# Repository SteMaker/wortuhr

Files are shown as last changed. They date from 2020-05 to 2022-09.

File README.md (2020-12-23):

# Wortuhr
Wortuhr basierend auf ESP-12F inkl. Firmware, PCB und Hardware-Beschreibung.

Ich übernehme keinerlei Verantwortung für die Funktionsfähigkeit und Sicherheit dieses Projekts. Jeder, der es nachbaut, ist selbst dafür verantwortlich!

Die Idee und insbesondere die Anordnung der Buchstaben habe ich mir im FabLab Nürnberg abgeschaut. Vielen Dank an der Stelle an den Unbekannten! :)

Die Hardware besteht aus 11 LED-Streifen à 11 LEDs vom Typ WS2812, die RGB fähig sind. Als Controller dient ein ESP-12F (ESP8266), der sich die Uhrzeit über das Internet per NTP holt. Die Konfiguration wird über ein Webinterface vorgenommen. Ein Helligkeitssensor wird verwendet, um die Helligkeit der Uhr (falls gewünscht) automatisch anzupassen. Es gibt auch eine Möglichkeit die Uhr zu einer bestimmten Zeit dunkel zu schalten, und zu einer anderen Zeit wieder zu aktivieren. Außerdem kann man die Farbe der LEDs pro Wort einstellen.

## Weitere Infos und die Bauanleitung sind im [Wiki](https://github.com/SteMaker/wortuhr/wiki)

## Aufbau
Als LED-Streifen werden WS2812 verwendet. Für jede der 11 Zeilen wird ein Streifen mit 11 LEDs verwendet. Die Spannungsversorgung habe ich für jeden Streifen einzeln auf die Hauptplatine gezogen, die Datenleitung muss von `Dout` des einen Streifens zum `Din` des Streifens der nächsten Zeile gezogen werden. Der `Din` der ersten Zeile muss rechts oben liegen und wird mit dem Controller verbunden. Von der linken Seite der ersten Zeile geht dann der `Dout` zum `Din` der linken Seite des zweiten Streifens, usw. Das ist wichtig, da sonst die falschen Buchstaben aufleuchten. Ich verwende LED Streifen mit 60 LEDs pro Meter.

Die Buchstabenmatrix habe ich mit einem 3D-Drucker ausgedruckt. Die STL-Dateien sowie die SVG-Basis liegen im Ordner `rahmen`. Es gibt eine Rückseite, in die die 11 LED-Streifen geklebt werden und eine Vorderseite mit den Aussparungen für die Buchstaben. Das Ganze kommt dann in einen Bilderrahmen. Der IKEA RIBBA 23x23 passt perfekt.

Alternativ kann die Frontplatte aus lackiertem Acrylglas gelasert werden.

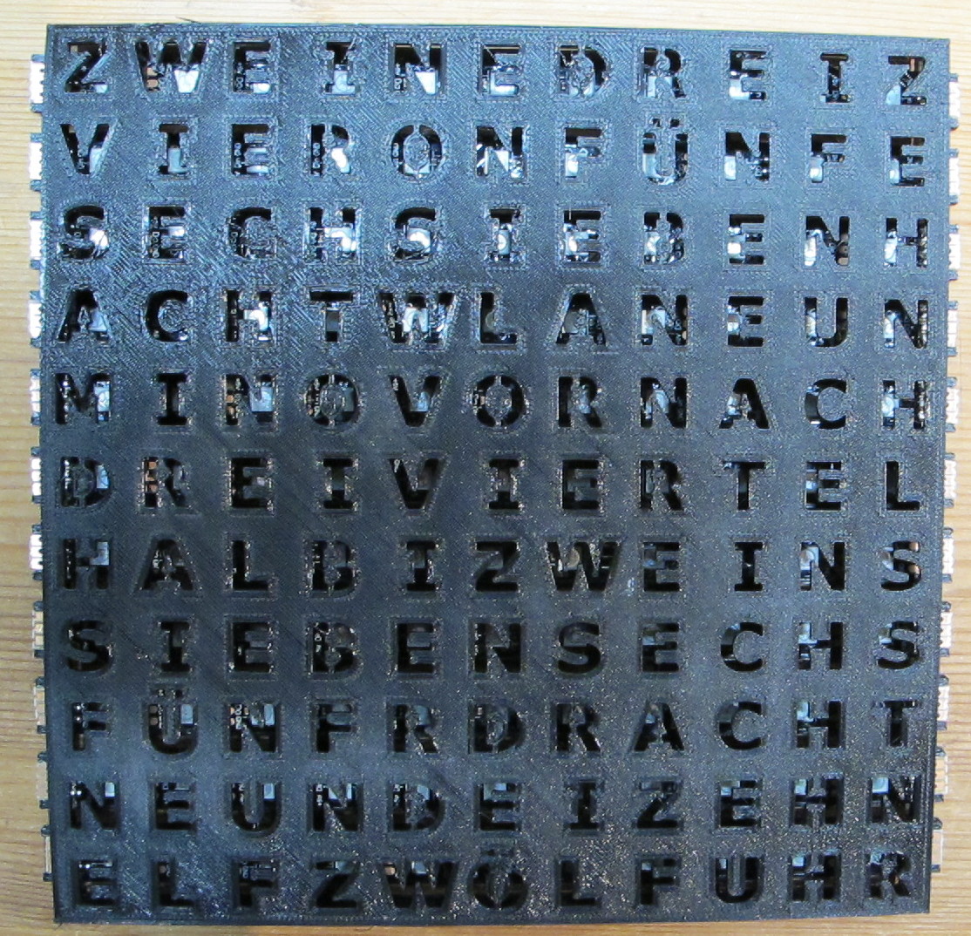
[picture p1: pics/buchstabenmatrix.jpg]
Buchstabenmatrix


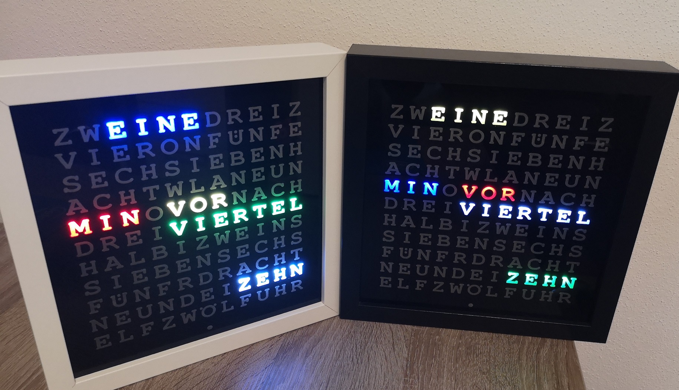
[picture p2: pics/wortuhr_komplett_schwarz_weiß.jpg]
Wortuhr mit gelaserter Acrylfront


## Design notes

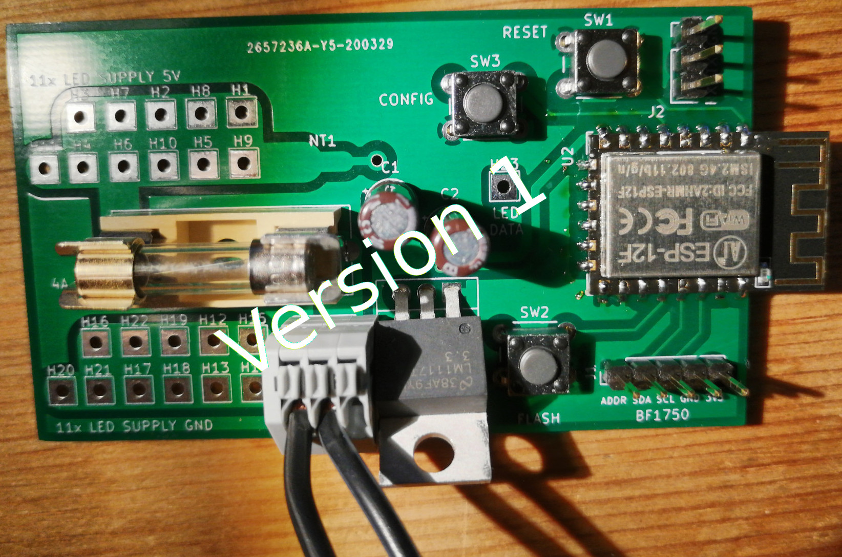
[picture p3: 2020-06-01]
pics/pcb1.jpg

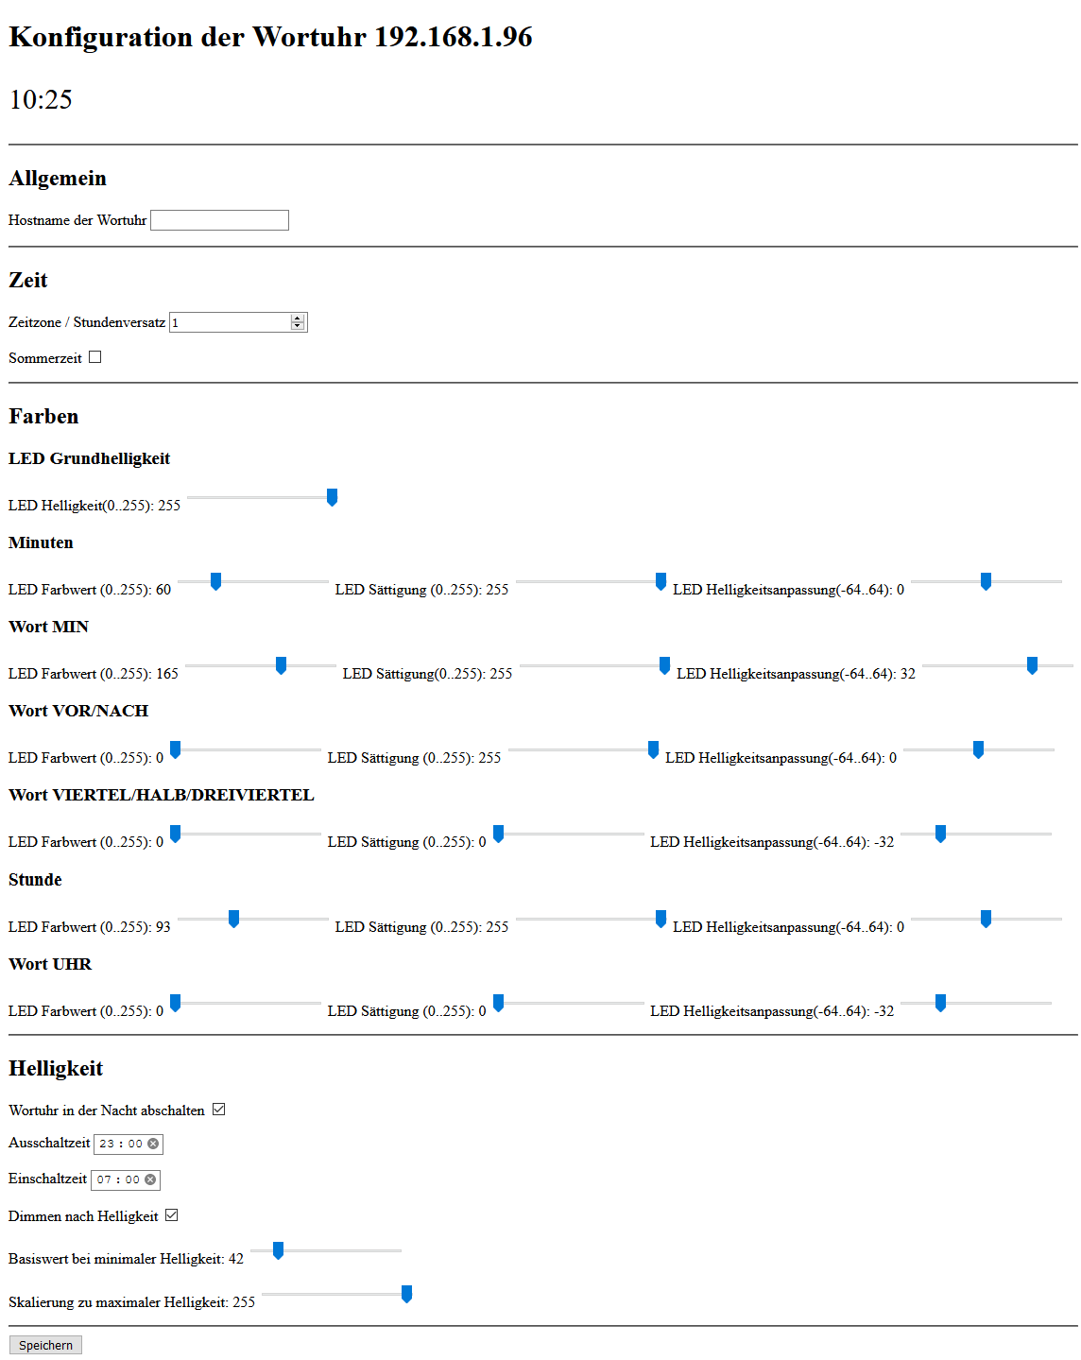
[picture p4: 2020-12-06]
pics/konfiguration.png

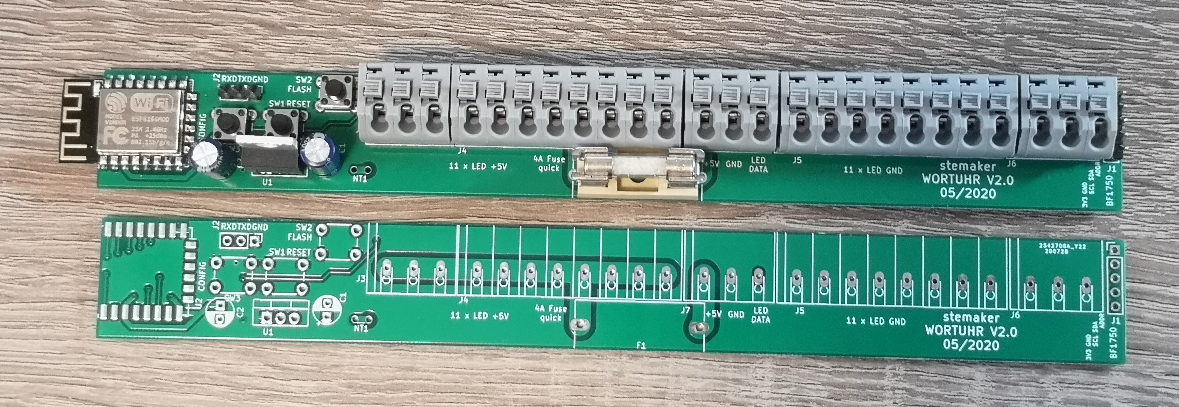
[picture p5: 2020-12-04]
pics/pcb_v2.jpg

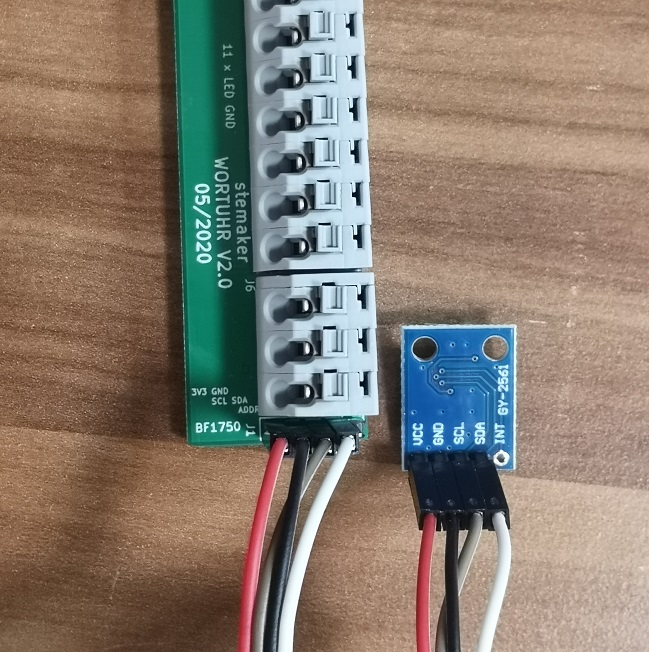
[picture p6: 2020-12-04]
pics/anschluss_helligkeitssensor_tsl2561.jpg

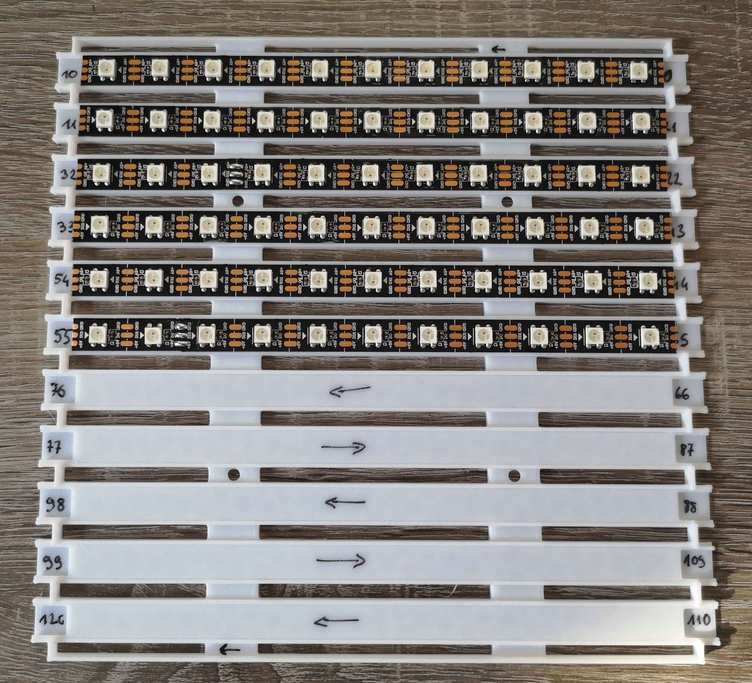
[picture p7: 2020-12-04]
pics/rueckseite_bestueckt_richtung.jpg

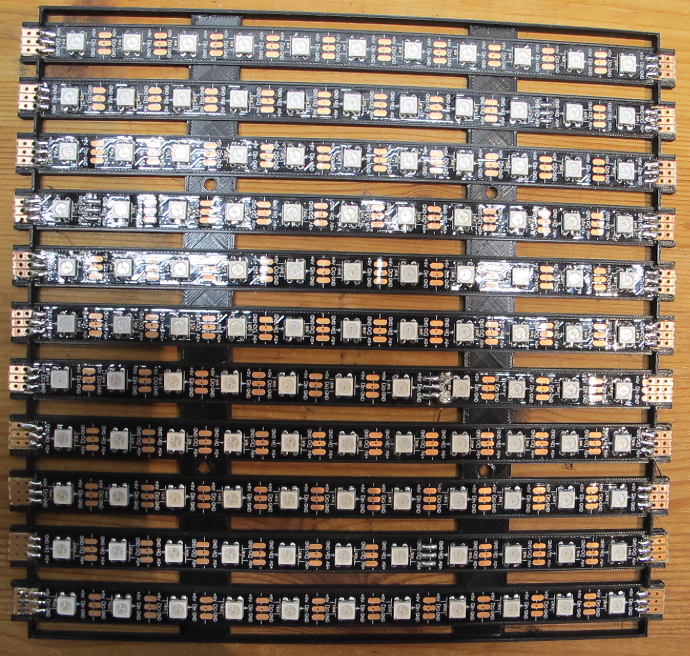
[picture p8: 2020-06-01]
pics/rueckseite_bestueckt.jpg

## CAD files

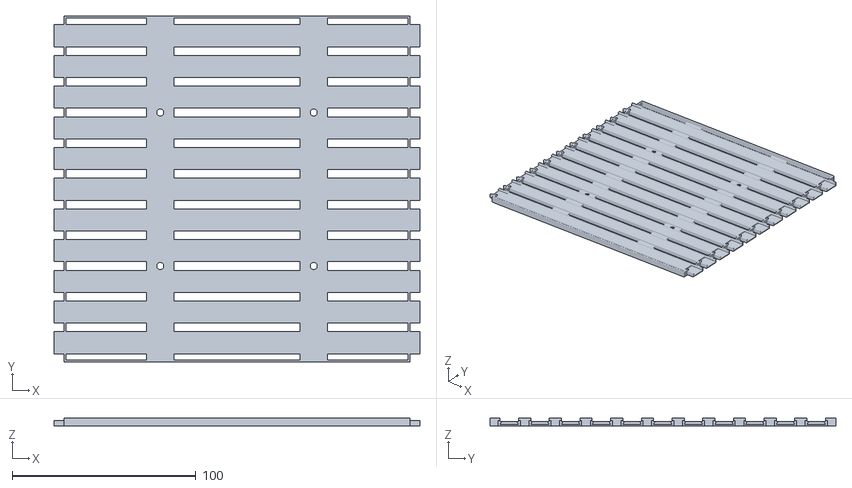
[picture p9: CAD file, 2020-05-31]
rahmen/Wortuhr_Rückteil.stl
199.0 x 188.0 x 4.60

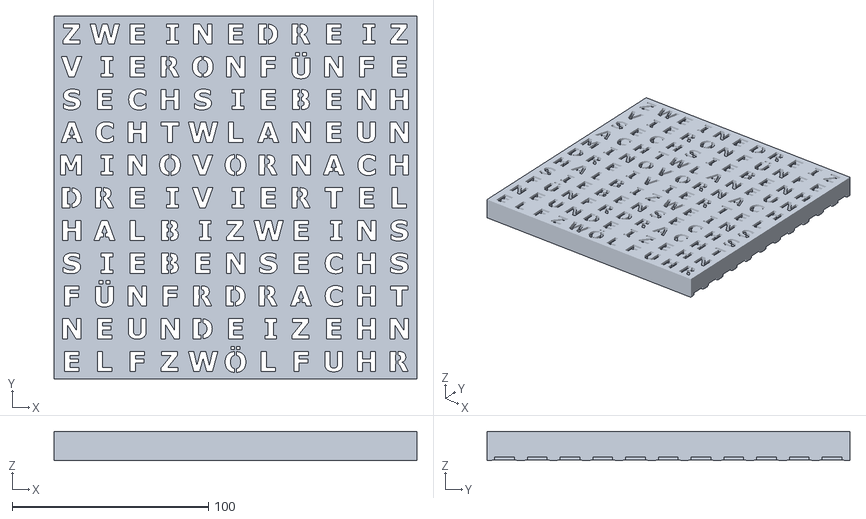
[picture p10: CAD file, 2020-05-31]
rahmen/Wortuhr_Vorderteil.stl
185.0 x 185.0 x 15.0

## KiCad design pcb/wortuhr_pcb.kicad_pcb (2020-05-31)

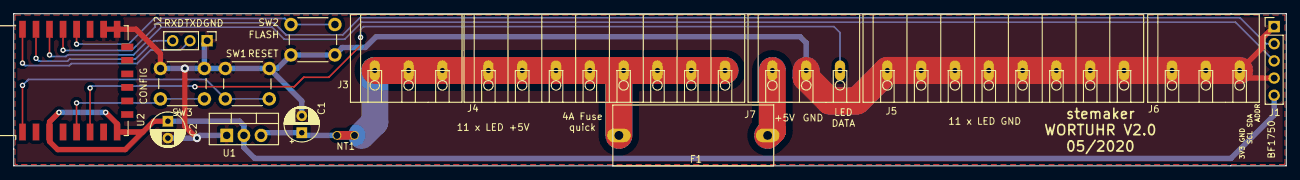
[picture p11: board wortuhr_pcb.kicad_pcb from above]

Board: 2 copper layers, 188.2 x 22.5 mm, 16 parts (0 on the bottom side), 13 nets.

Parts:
C1, C2: 1µF; CP_Radial_D5.0mm_P2.50mm
F1: Fuse; RND_fuse_holder_5x20mm_horizontal
J1: Conn_01x05_Male; PinHeader_1x05_P2.54mm_Vertical
J2: Conn_01x03_Male; PinHeader_1x03_P2.54mm_Vertical
J3, J6, J7: Conn_01x03_Male; WAGO_250-503
J4, J5: Conn_01x08_Male; WAGO_250-508
NT1: Net-Tie_2; NetTie-2_THT_Pad1.0mm
SW1, SW2, SW3: SW_Push; SW_PUSH_6mm_H4.3mm
U1: LM1117-3.3; TO-220-3_Vertical
U2: ESP-12F; ESP-12E

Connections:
+3V3: C2.1, J1.5, U1.2, U2.3, U2.8
+5V: C1.1, NT1.2, U1.3
/CFG: SW3.1, U2.5
/FLASH: SW2.1, U2.18
/LED_5V: F1.1, J3.1, J3.2, J3.3, J4.1, J4.2, J4.3, J4.4, J4.5, J4.6, J4.7, J4.8, NT1.1
/LED_DATA: J7.3, U2.6
/MAIN_SUPPLY: F1.2, J7.1
/RESET: SW1.2, U2.1
/RXD: J2.3, U2.21
/SCL: J1.3, U2.20
/SDA: J1.2, U2.19
/TXD: J2.2, U2.22
GND: C1.2, C2.2, J1.1, J1.4, J2.1, J5.1, J5.2, J5.3, J5.4, J5.5, J5.6, J5.7, J5.8, J6.1, J6.2, J6.3, J7.2, SW1.1, SW2.2, SW3.2, U1.1, U2.15, U2.16

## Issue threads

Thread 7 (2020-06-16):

Exception if clock is booted while website is loaded in browser

stan23, 2020-06-16:
If the wordclock website is open in a browser while the wordclock is powered up and booted, there's an exception.

First `NO WLAN` is shown, then `WLAN`, then the exception happens and the clock reboots.

Stack trace:
```
Exception 9: LoadStoreAlignmentCause: Load or store to an unaligned address
PC: 0x4010565c
EXCVADDR: 0x00000003

Decoding stack results
0x40220cb1: dns_gethostbyname_addrtype at core/dns.c line 1502
0x40220d08: dns_gethostbyname at core/dns.c line 1530
0x40229040: mem_free at core/mem.c line 237
0x402226f4: tcp_input at core/tcp_in.c line 501
0x402282ce: ip4_input at core/ipv4/ip4.c line 1467
0x4021f195: ethernet_input_LWIP2 at netif/ethernet.c line 188
0x4021efb4: esp2glue_ethernet_input at glue-lwip/lwip-git.c line 469
0x402449ce: ethernet_input at glue-esp/lwip-esp.c line 365
0x402449df: ethernet_input at glue-esp/lwip-esp.c line 373
0x4021eb79: glue2esp_linkoutput at glue-esp/lwip-esp.c line 301
0x4021ee02: new_linkoutput at glue-lwip/lwip-git.c line 260
0x4021f220: ethernet_output at netif/ethernet.c line 312
0x40229020: mem_malloc at core/mem.c line 210
0x4021f275: do_memp_malloc_pool at core/memp.c line 255
0x4021f2b4: memp_malloc at core/memp.c line 356
0x40226ad7: etharp_query at core/ipv4/etharp.c line 1031
0x4021eb79: glue2esp_linkoutput at glue-esp/lwip-esp.c line 301
0x40226c48: etharp_output_LWIP2 at core/ipv4/etharp.c line 890
0x40228530: ip4_output_if_opt_src at core/ipv4/ip4.c line 1764
0x4021f220: ethernet_output at netif/ethernet.c line 312
0x402285c6: ip4_output_if_src at core/ipv4/ip4.c line 1590
0x4022912b: ip_chksum_pseudo at core/inet_chksum.c line 395
0x402235ec: udp_sendto_if_src at core/udp.c line 893
0x40223643: udp_sendto_if at core/udp.c line 692
0x402236dc: udp_sendto at core/udp.c line 599
0x402206ba: dns_send at core/dns.c line 850
0x4022079b: dns_check_entry at core/dns.c line 1096
0x40220cb1: dns_gethostbyname_addrtype at core/dns.c line 1502
```

```
Exception 9: LoadStoreAlignmentCause: Load or store to an unaligned address
PC: 0x4010565c
EXCVADDR: 0x00000003

Decoding stack results
0x40229040: mem_free at core/mem.c line 237
0x402226f4: tcp_input at core/tcp_in.c line 501
0x402282ce: ip4_input at core/ipv4/ip4.c line 1467
0x4021f195: ethernet_input_LWIP2 at netif/ethernet.c line 188
0x4021efb4: esp2glue_ethernet_input at glue-lwip/lwip-git.c line 469
0x402449ce: ethernet_input at glue-esp/lwip-esp.c line 365
0x402449df: ethernet_input at glue-esp/lwip-esp.c line 373
0x4021eb79: glue2esp_linkoutput at glue-esp/lwip-esp.c line 301
0x4021ee02: new_linkoutput at glue-lwip/lwip-git.c line 260
0x4021f220: ethernet_output at netif/ethernet.c line 312
0x4021eb79: glue2esp_linkoutput at glue-esp/lwip-esp.c line 301
0x4021ee02: new_linkoutput at glue-lwip/lwip-git.c line 260
0x4021f220: ethernet_output at netif/ethernet.c line 312
0x4022912b: ip_chksum_pseudo at core/inet_chksum.c line 395
0x40229020: mem_malloc at core/mem.c line 210
0x4021f275: do_memp_malloc_pool at core/memp.c line 255
0x4021f2b4: memp_malloc at core/memp.c line 356
0x40226ad7: etharp_query at core/ipv4/etharp.c line 1031
0x40223643: udp_sendto_if at core/udp.c line 692
0x40226c48: etharp_output_LWIP2 at core/ipv4/etharp.c line 890
0x402206ba: dns_send at core/dns.c line 850
0x40228530: ip4_output_if_opt_src at core/ipv4/ip4.c line 1764
0x4022079b: dns_check_entry at core/dns.c line 1096
0x402285c6: ip4_output_if_src at core/ipv4/ip4.c line 1590
0x4022912b: ip_chksum_pseudo at core/inet_chksum.c line 395
0x402235ec: udp_sendto_if_src at core/udp.c line 893
0x40223643: udp_sendto_if at core/udp.c line 692
0x402236dc: udp_sendto at core/udp.c line 599
```

SteMaker, 2020-06-16:
Crash seems to occur here: https://github.com/SteMaker/wortuhr/blob/master/fw/src/main.cpp#L148.

SteMaker, 2020-06-28:
There is a potential fix on branch add_locks_issues_7. I couldn't reproduce any longer, but was rarely able to reproduce anyway. @stan23 Can you retest with this change?

stan23, 2020-06-28:
Just tried it, 0 crashes out of 10 reboots.
Without the fix it crashed 2 of 5 times.

SteMaker, 2020-07-05:
Fixed with 06bdd98a2ad62b2d2af1609e76567b8c02e3f333

Closed 2020-07-05.

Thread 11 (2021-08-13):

delay() does not work all the time

stan23, 2021-08-13:
Last year when I implemented `showIP()` the `delay()` worked fine, but now is does not wait long enough once Wifi is connected.

It happens with both Arduino Core 2.x and 3.x.

```
Connecting to SSID: TheresNoPlaceLike127001
showNoWlan
DBG: delay of 500 ms took 500 ms
.
DBG: delay of 500 ms took 500 ms
.
DBG: delay of 500 ms took 500 ms
.
DBG: delay of 500 ms took 500 ms
.
DBG: delay of 500 ms took 500 ms
.
DBG: delay of 500 ms took 500 ms
.
DBG: delay of 500 ms took 500 ms
.
showWlan                  <-- from here Wifi is connected
DBG: delay of 1000 ms took 0 ms
I2C device found at address 0x39
IP Address: 192.168.1.109
showIp: 192.168.1.109
DBG: delay of 750 ms took 0 ms
DBG: delay of 750 ms took 0 ms
DBG: delay of 750 ms took 0 ms
DBG: delay of 1000 ms took 0 ms
DBG: delay of 750 ms took 0 ms
DBG: delay of 750 ms took 0 ms
DBG: delay of 750 ms took 0 ms
DBG: delay of 1000 ms took 0 ms
DBG: delay of 750 ms took 0 ms
DBG: delay of 1000 ms took 0 ms
DBG: delay of 750 ms took 0 ms
DBG: delay of 750 ms took 0 ms
DBG: delay of 750 ms took 0 ms
DBG: delay of 1000 ms took 0 ms
Setup done
```

**Impact:**
As shown in the log above, the IP address is flashed within almost no time and hardly visible to the user.

**Root cause analysis:**
`esp_yield()` returns almost immediately and therefore `delay()` returns almost immediately.
Might be related to Wifi behavior impacting the schedule.
I have not found any other bug report on a similar topic.

**Possible solution:**
Change `showIP()` implementation so that it does not rely on `delay()`, which is bad design anyway.
https://github.com/esp8266/Arduino/blob/master/cores/esp8266/core_esp8266_wiring.cpp#L53

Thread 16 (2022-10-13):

Initial upload nicht möglich

Dave2526, 2022-10-13:
Hallo, ich versuche gerade den Intitial Upload zu starten, jedoch kommt immer die unten gezeigt Fehlermeldung. Ich finde lieder keine brauchbare Hilfe dieses Problem zu lösen...

 *  Task wird ausgeführt: C:\Users\User\.platformio\penv\Scripts\platformio.exe run --target upload --environment inital_upload

Processing inital_upload (platform: espressif8266@^2; board: esp12e; framework: arduino)
-----------------------------------------------------------------------------------------------------------------------------------------------------------------------------
Verbose mode can be enabled via `-v, --verbose` option
CONFIGURATION: https://docs.platformio.org/page/boards/espressif8266/esp12e.html
PLATFORM: Espressif 8266 (2.7.4+9) > Espressif ESP8266 ESP-12E
HARDWARE: ESP8266 80MHz, 80KB RAM, 4MB Flash
PACKAGES:
 - framework-arduinoespressif8266 @ 2.7.4+9
 - tool-esptool @ 1.413.0 (4.13)
 - tool-esptoolpy @ 1.30300.220323 (3.3.0)
 - tool-mklittlefs @ 1.203.200522 (2.3)
 - tool-mkspiffs @ 1.200.0 (2.0)
 - toolchain-xtensa @ 2.40802.200502 (4.8.2)
LDF: Library Dependency Finder -> https://bit.ly/configure-pio-ldf
LDF Modes: Finder ~ chain, Compatibility ~ soft
Found 38 compatible libraries
Scanning dependencies...
Dependency Graph
|-- NTPClient @ 3.2.1+sha.78d4237
|-- FastLED @ 3.5.0+sha.0838804
|   |-- SPI @ 1.0
|   |-- EspSoftwareSerial @ 6.10.0
|-- ESP Async WebServer @ 1.2.3+sha.f71e3d4
|   |-- ESPAsyncTCP @ 1.2.2
|   |   |-- ESP8266WiFi @ 1.0
|   |-- Hash @ 1.0
|   |-- ESP8266WiFi @ 1.0
|-- ESP_EEPROM @ 2.1.2+sha.63796bc
|-- CRCx @ 0.3.2+sha.ccaab2a
|-- BH1750FVI @ 1.1.1+sha.1e18959
|   |-- Wire @ 1.0
|-- TSL2561 Arduino Library @ 1.0.0+sha.fea818e
|   |-- Wire @ 1.0
|-- ArduinoJson
|-- ESP8266WiFi @ 1.0
|-- ESPAsyncTCP @ 1.2.2
|   |-- ESP8266WiFi @ 1.0
|-- Wire @ 1.0
|-- ArduinoOTA @ 1.0
|   |-- ESP8266WiFi @ 1.0
|   |-- ESP8266mDNS @ 1.2
|   |   |-- ESP8266WiFi @ 1.0
Building in release mode
Compiling .pio\build\inital_upload\src\main.cpp.o
Compiling .pio\build\inital_upload\lib45a\SoftwareSerial\SoftwareSerial.cpp.o
Compiling .pio\build\inital_upload\libd78\ESP8266WiFi\ESP8266WiFiSTA.cpp.o
Compiling .pio\build\inital_upload\libd78\ESP8266WiFi\ESP8266WiFiScan.cpp.o
Compiling .pio\build\inital_upload\libd78\ESP8266WiFi\WiFiClient.cpp.o
Compiling .pio\build\inital_upload\libd78\ESP8266WiFi\WiFiClientSecureAxTLS.cpp.o
Compiling .pio\build\inital_upload\libd78\ESP8266WiFi\WiFiClientSecureBearSSL.cpp.o
Compiling .pio\build\inital_upload\libd78\ESP8266WiFi\WiFiServer.cpp.o
src\main.cpp:2:25: fatal error: ArduinoJson.h: No such file or directory

*********************************************************************
* Looking for ArduinoJson.h dependency? Check our library registry!
*
* CLI  > platformio lib search "header:ArduinoJson.h"
* Web  > https://registry.platformio.org/search?q=header:ArduinoJson.h
*
*********************************************************************

 #include <ArduinoJson.h>
                         ^
compilation terminated.
*** [.pio\build\inital_upload\src\main.cpp.o] Error 1
In file included from C:\Users\User\.platformio\packages\framework-arduinoespressif8266@2.7.4+9\libraries\SoftwareSerial\src\SoftwareSerial.cpp:23:0:
C:\Users\User\.platformio\packages\framework-arduinoespressif8266@2.7.4+9\libraries\SoftwareSerial\src\SoftwareSerial.h:132:9: error: 'int SoftwareSerial::availableForWrite()' marked override, but does not override
     int availableForWrite() override {
         ^
*** [.pio\build\inital_upload\lib45a\SoftwareSerial\SoftwareSerial.cpp.o] Error 1
======================================================================== [FAILED] Took 6.10 seconds ========================================================================

Environment    Status    Duration
-------------  --------  ------------
inital_upload  FAILED    00:00:06.098

stan23, 2022-10-13:
Aus irgendeinem Grund hat PlatformIO nicht die Lib "ArduinoJson" installiert.

Kannst du zum Test die Zeile https://github.com/SteMaker/wortuhr/blob/master/fw/platformio.ini#L28 durch "bblanchon/ArduinoJson" ersetzen?
Wenn das nicht hilft, dann direkt in PlatformIO diese Lib installieren?

Den zweiten Fehler ("override") verstehe ich momentan nicht.

Dave2526, 2022-10-13:
AdrduinoJson Fehler ist weg, der andere allerdings noch da...

Closed 2022-10-13.

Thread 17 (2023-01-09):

Ikea RIBBA Rahmen nicht mehr erhältlich

Dave2526, 2023-01-09:
Hallo,
Nur zur Info:
IKEA hat die RIBBA Rahmen leider aus dem Lieferprogramm genommen, der HOVSTA passt allerdings auch (fast). Nur das Passepartout muss größer geschnitten werden und die Buchstabenfront sollte niedriger gedruckt werden. Wie viel niedriger kann ich leider nicht sagen, habe es vor dem Rahmenkauf gedruckt. DIe Wortuhr ist auch so montierbar, allerdings drückt es dann das Plexiglas etwas heraus.

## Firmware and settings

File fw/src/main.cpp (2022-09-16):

#include <Arduino.h>
#include <ArduinoJson.h>
#include <AsyncJson.h>
#include <ESP8266WiFi.h>
#include <ESPAsyncTCP.h>
#include <ESPAsyncWebServer.h>
#include <stdlib.h>

#include "LedCtrl.h"
#include "Ota.h"
#include "Persistent.h"
#include "TimeGetter.h"
#include "Brightness.h"
#include "html_cfg.h"
#include "html_wifi_cfg.h"

// window size for the moving average calculation for the measured brightness (less than 255)
#define LUMA_SCALE_MOVING_AVG_WIN_SIZE    16

enum Mode { MODE_INITIAL_CONFIG, MODE_NORMAL };

/* VARIABLES */
Mode mode;

LedCtrl ledCtrl;
Ota ota;
TimeGetter timeGetter;
AsyncWebServer server(80);
Persistent persistent;
Brightness brightness;

bool factoryReset = false;
bool testAllWords = false;

void ICACHE_RAM_ATTR cfgBtnPressed(void) {
  factoryReset = true;
}

void notFound(AsyncWebServerRequest *request) {
  request->send(404, "text/plain", "Not found");
}

void getTime(int &h, int &m) {
    timeGetter.getTime(h, m);
    h += persistent.timeZoneOffset();
    if (persistent.dayLightSaving() == 1) {   // manual DST
      h += 1;
    };
    if (persistent.dayLightSaving() == 2) {   // automatic DST
      h += timeGetter.getDst();
    };
}

void setupForInitialConfig(void) {
  mode = MODE_INITIAL_CONFIG;

  IPAddress local_IP(192, 168, 25, 1);
  IPAddress gateway(192, 168, 25, 1);
  IPAddress subnet(255, 255, 255, 0);

  // Enable WiFi accesspoint so that user can configure its WiFi SSID and
  // password
  WiFi.softAPConfig(local_IP, gateway, subnet);
  WiFi.softAP("WORTUHR_AP");
  Serial.print("softAP IP:");
  Serial.println(WiFi.softAPIP());

  ledCtrl.setup();
  ledCtrl.showWlan(CRGB::Blue);

  server.on("/", HTTP_GET, [](AsyncWebServerRequest *request) {
    Serial.println("Client connected");
    request->send(200, "text/html", FPSTR(htmlCfgWifi));
  });

  server.on("/", HTTP_POST, [](AsyncWebServerRequest *request) {
    Serial.println("Configuration set");
    if (request->hasParam("ssid", true)) {
      persistent.ssid(request->getParam("ssid", true)->value().c_str());
      Serial.print("SSID set to: ");
      Serial.println(persistent.ssid().c_str());
      request->send(200, "text/html", FPSTR(htmlCfgWifiConfirm));
    } else {
      request->send(200, "text/html", FPSTR(htmlCfgReject));
      Serial.println("No SSID");
    }
    if (request->hasParam("passwd", true)) {
      persistent.wifiPwd(request->getParam("passwd", true)->value().c_str());
      Serial.print("WiFi password set to: ");
      Serial.println(persistent.wifiPwd().c_str());
    } else {
      Serial.println("No WiFi password");
    }
    persistent.updateToFlash();
    ESP.restart();
  });

  delay(3000);                  // show "WLAN" before displaying the IP
  ledCtrl.showIp(local_IP);
  ledCtrl.showWlan(CRGB::Blue); // show "WLAN" once again until the user finishes the configuration
}

void setColorFromJson(JsonObject &jsonObj, bool persist) {
  // Luma
  uint8_t luma = persistent.luma();
  if (jsonObj.containsKey("luma")) {
    luma = jsonObj["luma"];
    if (persist) persistent.luma(luma);
  } else {
    Serial.println("No Luma value found");
  }

  // colorMinutesNumeral
  Persistent::Color c;
  c = persistent.color(Persistent::minutesNumeral);
  if (jsonObj.containsKey("colorMinutesNumeralHue")) {
    c.hue = jsonObj["colorMinutesNumeralHue"];
  }
  if (jsonObj.containsKey("colorMinutesNumeralSat")) {
    c.sat = jsonObj["colorMinutesNumeralSat"];
  }
  if (jsonObj.containsKey("colorMinutesNumeralLumaOffset")) {
    c.lumaOffset = jsonObj["colorMinutesNumeralLumaOffset"];
  }
  if (persist) persistent.color(Persistent::minutesNumeral, c);
  Serial.print("New colorMinutesNumeral: ");
  Serial.print("hue: ");
  Serial.print(c.hue);
  Serial.print(", sat: ");
  Serial.print(c.sat);
  Serial.print(", lumaOffset: ");
  Serial.println(c.lumaOffset);
  ledCtrl.setColor(LedCtrl::minutesNumeral, c.hue, c.sat, c.lumaOffset, luma);

  // colorMinWord
  c = persistent.color(Persistent::minWord);
  if (jsonObj.containsKey("colorMinWordHue")) {
    c.hue = jsonObj["colorMinWordHue"];
  }
  if (jsonObj.containsKey("colorMinWordSat")) {
    c.sat = jsonObj["colorMinWordSat"];
  }
  if (jsonObj.containsKey("colorMinWordLumaOffset")) {
    c.lumaOffset = jsonObj["colorMinWordLumaOffset"];
  }
  if (persist) persistent.color(Persistent::minWord, c);
  Serial.print("New colorMinWord: ");
  Serial.print("hue: ");
  Serial.print(c.hue);
  Serial.print(", sat: ");
  Serial.print(c.sat);
  Serial.print(", lumaOffset: ");
  Serial.println(c.lumaOffset);
  ledCtrl.setColor(LedCtrl::minWord, c.hue, c.sat, c.lumaOffset, luma);

  // colorPreWord
  c = persistent.color(Persistent::preWord);
  if (jsonObj.containsKey("colorPreWordHue")) {
    c.hue = jsonObj["colorPreWordHue"];
  }
  if (jsonObj.containsKey("colorPreWordSat")) {
    c.sat = jsonObj["colorPreWordSat"];
  }
  if (jsonObj.containsKey("colorPreWordLumaOffset")) {
    c.lumaOffset = jsonObj["colorPreWordLumaOffset"];
  }
  if (persist) persistent.color(Persistent::preWord, c);
  Serial.print("New colorPreWord: ");
  Serial.print("hue: ");
  Serial.print(c.hue);
  Serial.print(", sat: ");
  Serial.print(c.sat);
  Serial.print(", lumaOffset: ");
  Serial.println(c.lumaOffset);
  ledCtrl.setColor(LedCtrl::preWord, c.hue, c.sat, c.lumaOffset, luma);

  // quarterWord
  c = persistent.color(Persistent::quarterWord);
  if (jsonObj.containsKey("colorQuarterWordHue")) {
    c.hue = jsonObj["colorQuarterWordHue"];
  }
  if (jsonObj.containsKey("colorQuarterWordSat")) {
    c.sat = jsonObj["colorQuarterWordSat"];
  }
  if (jsonObj.containsKey("colorQuarterWordLumaOffset")) {
    c.lumaOffset = jsonObj["colorQuarterWordLumaOffset"];
  }
  if (persist) persistent.color(Persistent::quarterWord, c);
  Serial.print("New colorQuarterWord: ");
  Serial.print("hue: ");
  Serial.print(c.hue);
  Serial.print(", sat: ");
  Serial.print(c.sat);
  Serial.print(", lumaOffset: ");
  Serial.println(c.lumaOffset);
  ledCtrl.setColor(LedCtrl::quarterWord, c.hue, c.sat, c.lumaOffset, luma);

  // hoursNumeral
  c = persistent.color(Persistent::hoursNumeral);
  if (jsonObj.containsKey("colorHoursNumeralHue")) {
    c.hue = jsonObj["colorHoursNumeralHue"];
  }
  if (jsonObj.containsKey("colorHoursNumeralSat")) {
    c.sat = jsonObj["colorHoursNumeralSat"];
  }
  if (jsonObj.containsKey("colorHoursNumeralLumaOffset")) {
    c.lumaOffset = jsonObj["colorHoursNumeralLumaOffset"];
  }
  if (persist) persistent.color(Persistent::hoursNumeral, c);
  Serial.print("New colorHoursNumeral: ");
  Serial.print("hue: ");
  Serial.print(c.hue);
  Serial.print(", sat: ");
  Serial.print(c.sat);
  Serial.print(", lumaOffset: ");
  Serial.println(c.lumaOffset);
  ledCtrl.setColor(LedCtrl::hoursNumeral, c.hue, c.sat, c.lumaOffset, luma);

  // clockWord
  c = persistent.color(Persistent::clockWord);
  if (jsonObj.containsKey("colorClockWordHue")) {
    c.hue = jsonObj["colorClockWordHue"];
  }
  if (jsonObj.containsKey("colorClockWordSat")) {
    c.sat = jsonObj["colorClockWordSat"];
  }
  if (jsonObj.containsKey("colorClockWordLumaOffset")) {
    c.lumaOffset = jsonObj["colorClockWordLumaOffset"];
  }
  if (persist) persistent.color(Persistent::clockWord, c);
  Serial.print("New colorClockWord: ");
  Serial.print("hue: ");
  Serial.print(c.hue);
  Serial.print(", sat: ");
  Serial.print(c.sat);
  Serial.print(", lumaOffset: ");
  Serial.println(c.lumaOffset);
  ledCtrl.setColor(LedCtrl::clockWord, c.hue, c.sat, c.lumaOffset, luma);

  ledCtrl.forceUpdate = true;
}

char configBuffer[1080]; // 1080 comes from ArduinoJson Assistant
char timedBuffer[75]; // 75 comes from ArduinoJson Assistant
void setupForNormal(void) {
  mode = MODE_NORMAL;

  Serial.print("Connecting to SSID: ");
  Serial.println(persistent.ssid().c_str());

  ledCtrl.setup();
  ledCtrl.showNoWlan();

  // Set WiFi to station mode and disconnect from an AP if it was previously
  // connected
  WiFi.mode(WIFI_STA);
  if (strcmp(persistent.hostname().c_str(), ""))
    WiFi.hostname(persistent.hostname().c_str());
  WiFi.begin(persistent.ssid().c_str(), persistent.wifiPwd().c_str());
  while (WiFi.status() != WL_CONNECTED) {
    delay(500);
    Serial.print(".");
    if(factoryReset) {
      factoryReset = false;
      ledCtrl.clear();
      persistent.factoryReset();
      ESP.restart();
    }
  }
  ledCtrl.showWlan();
  delay(1000);  // indicate the connection before switching to the time

  ota.setup();
  timeGetter.setup();
  brightness.setup(persistent.dim().base, persistent.dim().scale);

  // Serving the standard configuration page
  server.on("/", HTTP_GET, [](AsyncWebServerRequest *request) {
    Serial.println("Client connected");
    Serial.print("  free heap: ");
    Serial.println(ESP.getFreeHeap());
    Serial.print("  fragmentation: ");
    Serial.println(ESP.getHeapFragmentation());
    Serial.print("  max block size: ");
    Serial.println(ESP.getMaxFreeBlockSize());

    request->send_P(200, "text/html", htmlCfg);
    Serial.print("size of the page that was sent: ");
    Serial.println(sizeof(htmlCfg));
    Serial.print("  free heap: ");
    Serial.println(ESP.getFreeHeap());
    Serial.print("  fragmentation: ");
    Serial.println(ESP.getHeapFragmentation());
    Serial.print("  max block size: ");
    Serial.println(ESP.getMaxFreeBlockSize());
  });

  server.on("/config", HTTP_GET, [](AsyncWebServerRequest *request) {
    Serial.println("Configuration requested");
    const size_t capacity =
        JSON_OBJECT_SIZE(31);  // adjust to the number of elements
    DynamicJsonDocument doc(capacity);
    doc["hostname"] = persistent.hostname().c_str();
    doc["showIp"] = persistent.showIp();
    doc["timeZoneOffset"] = persistent.timeZoneOffset();
    doc["dayLightSaving"] = persistent.dayLightSaving();
    doc["luma"] = persistent.luma();
    doc["colorMinutesNumeralHue"] =
        persistent.color(Persistent::minutesNumeral).hue;
    doc["colorMinutesNumeralSat"] =
        persistent.color(Persistent::minutesNumeral).sat;
    doc["colorMinutesNumeralLumaOffset"] =
        persistent.color(Persistent::minutesNumeral).lumaOffset;
    doc["colorMinWordHue"] = persistent.color(Persistent::minWord).hue;
    doc["colorMinWordSat"] = persistent.color(Persistent::minWord).sat;
    doc["colorMinWordLumaOffset"] =
        persistent.color(Persistent::minWord).lumaOffset;
    doc["colorPreWordHue"] = persistent.color(Persistent::preWord).hue;
    doc["colorPreWordSat"] = persistent.color(Persistent::preWord).sat;
    doc["colorPreWordLumaOffset"] =
        persistent.color(Persistent::preWord).lumaOffset;
    doc["colorQuarterWordHue"] = persistent.color(Persistent::quarterWord).hue;
    doc["colorQuarterWordSat"] = persistent.color(Persistent::quarterWord).sat;
    doc["colorQuarterWordLumaOffset"] =
        persistent.color(Persistent::quarterWord).lumaOffset;
    doc["colorHoursNumeralHue"] =
        persistent.color(Persistent::hoursNumeral).hue;
    doc["colorHoursNumeralSat"] =
        persistent.color(Persistent::hoursNumeral).sat;
    doc["colorHoursNumeralLumaOffset"] =
        persistent.color(Persistent::hoursNumeral).lumaOffset;
    doc["colorClockWordHue"] = persistent.color(Persistent::clockWord).hue;
    doc["colorClockWordSat"] = persistent.color(Persistent::clockWord).sat;
    doc["colorClockWordLumaOffset"] =
        persistent.color(Persistent::clockWord).lumaOffset;
    doc["nightOffActive"] = persistent.nightOff().active;
    doc["nightOffOffHour"] = persistent.nightOff().offHour;
    doc["nightOffOffMinute"] = persistent.nightOff().offMinute;
    doc["nightOffOnHour"] = persistent.nightOff().onHour;
    doc["nightOffOnMinute"] = persistent.nightOff().onMinute;
    doc["dimActive"] = persistent.dim().active;
    doc["dimBase"] = persistent.dim().base;
    doc["dimScale"] = persistent.dim().scale;
    // Serial.print("Size of configuration: ");
    // Serial.println(measureJson(doc));
    serializeJson(doc, configBuffer, sizeof(configBuffer));
    request->send(200, "application/json", configBuffer);
  });

  // show every possible word for one second as a test sequence
  server.on("/test", HTTP_GET, [](AsyncWebServerRequest *request) {
    testAllWords = true;
    const size_t capacity = JSON_OBJECT_SIZE(0);
    DynamicJsonDocument doc(capacity);
    serializeJson(doc, timedBuffer, sizeof(timedBuffer));
    request->send(200, "application/json", timedBuffer);
  });

  // time and light intensity getter
  server.on("/timedData", HTTP_GET, [](AsyncWebServerRequest *request) {
    const size_t capacity = JSON_OBJECT_SIZE(3);
    DynamicJsonDocument doc(capacity);
    int h, m;
    getTime(h, m);
    doc["timeH"] = h;
    doc["timeM"] = m;
    doc["lightIntensity"] = 0;
    serializeJson(doc, timedBuffer, sizeof(timedBuffer));
    request->send(200, "application/json", timedBuffer);
  });


  // retrieving the configuration
  AsyncCallbackJsonWebHandler *cfgHandler = new AsyncCallbackJsonWebHandler(
      "/config", [](AsyncWebServerRequest *request, JsonVariant &json) {
        Serial.println("Configuration received");
        JsonObject jsonObj = json.as<JsonObject>();
        if (jsonObj.containsKey("hostname")) {
          const char *hostname = jsonObj["hostname"];
             persistent.hostname(hostname);
        } else {
          Serial.println("No hostname found");
        }
        if (jsonObj.containsKey("showIp")) {
          bool showIp = jsonObj["showIp"];
          persistent.showIp(showIp);
        } else {
          Serial.println("No show IP found");
        }
        if (jsonObj.containsKey("timeZoneOffset")) {
          int timeZoneOffset = jsonObj["timeZoneOffset"];
          persistent.timeZoneOffset(timeZoneOffset);
        } else {
          Serial.println("No time zone offset found");
        }
        if (jsonObj.containsKey("dayLightSaving")) {
          uint8_t dayLightSaving = jsonObj["dayLightSaving"];
          persistent.dayLightSaving(dayLightSaving);
        } else {
          Serial.println("No day light saving found");
        }

        setColorFromJson(jsonObj, true);

        Persistent::NightOff no;
        if (jsonObj.containsKey("nightOffActive")) {
          no.active = jsonObj["nightOffActive"];
        }
        if (jsonObj.containsKey("nightOffOffHour")) {
          no.offHour = jsonObj["nightOffOffHour"];
        }
        if (jsonObj.containsKey("nightOffOffMinute")) {
          no.offMinute = jsonObj["nightOffOffMinute"];
        }
        if (jsonObj.containsKey("nightOffOnHour")) {
          no.onHour = jsonObj["nightOffOnHour"];
        }
        if (jsonObj.containsKey("nightOffOnMinute")) {
          no.onMinute = jsonObj["nightOffOnMinute"];
        }
        persistent.nightOff(no);

        Persistent::Dim d;
        if (jsonObj.containsKey("dimActive")) {
          d.active = jsonObj["dimActive"];
        }
        if (jsonObj.containsKey("dimBase")) {
          d.base = jsonObj["dimBase"];
        }
        if (jsonObj.containsKey("dimScale")) {
          d.scale = jsonObj["dimScale"];
        }
        persistent.dim(d);
        brightness.setScaleParams(d.base, d.scale);
        persistent.print();

        persistent.updateToFlash();
        request->send(200, "application/json", "{}");
      });
  server.addHandler(cfgHandler);

  // color setter
  AsyncCallbackJsonWebHandler *colorHandler = new AsyncCallbackJsonWebHandler(
      "/color", [](AsyncWebServerRequest *request, JsonVariant &json) {
        Serial.println("Color received");
        JsonObject jsonObj = json.as<JsonObject>();
        setColorFromJson(jsonObj, false);
        request->send(200, "application/json", "{}");
      });
  server.addHandler(colorHandler);

  if (persistent.showIp()) {
    Serial.print("IP Address: ");
    Serial.println(WiFi.localIP());
    ledCtrl.showIp(WiFi.localIP());
  }
}

void setup() {
    Serial.begin(115200);
    persistent.setup();

    pinMode(14, INPUT_PULLUP);
    attachInterrupt(digitalPinToInterrupt(14), cfgBtnPressed, FALLING);

    if (!strcmp(persistent.ssid().c_str(), "")) {
      setupForInitialConfig();
    } else {
      setupForNormal();
    }

    server.onNotFound(notFound);
    server.begin();

    Serial.println("Setup done");
}

// is (h2:m2) later or equal (h1:m1)
bool isLaterEqual(int h1, int m1, int h2, int m2) {
  if( (h2 > h1) || ((h2 == h1) && (m2 > m1)) || ((h2 == h1) && (m2 == m1)) )
      return true;
  return false;
}

bool withinActiveTimeWindow(int hour, int minute) {
  Persistent::NightOff no = persistent.nightOff();
  if(!no.active) return true;
  if(!isLaterEqual(no.offHour, no.offMinute, no.onHour, no.onMinute)) {
    // off time crosses midnight
    if(isLaterEqual(no.offHour, no.offMinute, hour, minute) ||
       !isLaterEqual(no.onHour, no.onMinute, hour, minute))
       return false;
    return true;
  } else {
    if(isLaterEqual(no.offHour, no.offMinute, hour, minute) &&
       !isLaterEqual(no.onHour, no.onMinute, hour, minute))
       return false;
    return true;
  }
}

void loop() {
    ota.loop();
    timeGetter.loop();
    if(factoryReset) {
      factoryReset = false;
      ledCtrl.clear();
      persistent.factoryReset();
      ESP.restart();
    }

    if (mode == MODE_NORMAL) {
      if (testAllWords) {
        testAllWords = false;
        ledCtrl.testAllWords();
      } else {
        int h;
        int m;
        getTime(h, m);

        static uint16_t lumaScale = 255;
        if(persistent.dim().active) {
          lumaScale = (brightness.getLumaScale() + lumaScale * (LUMA_SCALE_MOVING_AVG_WIN_SIZE - 1)) / LUMA_SCALE_MOVING_AVG_WIN_SIZE;
          ledCtrl.setLumaScale(lumaScale);
        } else {
          ledCtrl.setLumaScale(255);
        }

        static bool wasWithinActTimeWindow = false;
        bool isWithinActTimeWindow = withinActiveTimeWindow(h, m);
        if (isWithinActTimeWindow) 
          ledCtrl.setClock(h, m);
        else if (wasWithinActTimeWindow) {
          Serial.println("now out of active time window, turning LEDs off");
          ledCtrl.clear();
        }
        wasWithinActTimeWindow = isWithinActTimeWindow;

        //delay(250);
      }
    } else {
      static unsigned int timeout = 15*60*2;
      timeout--;
      if(!timeout) {
        // Disable the softAP after 15 minutes
        Serial.println("Disabling softAP");
        ledCtrl.showNoWlan();
        WiFi.mode(WIFI_OFF);
        WiFi.forceSleepBegin();
      }
      delay(500);
    }

}

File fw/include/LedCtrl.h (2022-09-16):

/*
  10 | ZWEINEDREIZ | 0
  11 | VIERONFUNFE | 21
  32 | SECHSIEBENH | 22
  33 | ACHTWLANEUN | 43
  54 | MINOVORNACH | 44
  55 | DREIVIERTEL | 65
  76 | HALBIZWEINS | 66
  77 | SIEBENSECHS | 87
  98 | FUNFRDRACHT | 88
  99 | NEUNDEIZEHN | 109
 120 | ELFZWOLFUHR | 110
*/

#include <FastLED.h>

#define NUM_LEDS 11*11
#define LED_DATA_PIN 12
#define MAX_WORD_LEN 12
#define MAX_NUM_WORDS 6
#define LED_OFF CRGB::Black

struct WordPattern {
  uint8_t pattern[MAX_WORD_LEN];
};

const WordPattern patterns[] = {
    {.pattern = {8, 7, 6, 5, 255}},                  // EINE
    {.pattern = {10, 9, 8, 7, 255}},                 // ZWEI
    {.pattern = {4, 3, 2, 1, 255}},                  // DREI
    {.pattern = {11, 12, 13, 14, 255}},              // VIER
    {.pattern = {17, 18, 19, 20, 255}},              // FUENF
    {.pattern = {32, 31, 30, 29, 28, 255}},          // SECHS
    {.pattern = {28, 27, 26, 25, 24, 23, 255}},      // SIEBEN
    {.pattern = {33, 34, 35, 36, 255}},              // ACHT
    {.pattern = {40, 41, 42, 43, 255}},              // NEUN
    {.pattern = {0, 21, 22, 43, 255}},               // ZEHN
    {.pattern = {69, 68, 67, 255}},                  // EIN
    {.pattern = {69, 68, 67, 66, 255}},              // EINS
    {.pattern = {71, 70, 69, 68, 255}},              // ZWEI
    {.pattern = {93, 92, 104, 105, 255}},            // DREI-SQUARE
    {.pattern = {59, 72, 81, 94, 255}},              // VIER
    {.pattern = {98, 97, 96, 95, 255}},              // FUENF
    {.pattern = {83, 84, 85, 86, 87, 255}},          // SECHS
    {.pattern = {77, 78, 79, 80, 81, 82, 255}},      // SIEBEN
    {.pattern = {91, 90, 89, 88, 255}},              // ACHT
    {.pattern = {99, 100, 101, 102, 255}},           // NEUN
    {.pattern = {106, 107, 108, 109, 255}},          // ZEHN
    {.pattern = {120, 119, 118, 255}},               // ELF
    {.pattern = {117, 116, 115, 114, 113, 255}},     // ZWOELF
    {.pattern = {50, 49, 48, 255}},                  // VOR
    {.pattern = {47, 46, 45, 44, 255}},              // NACH
    {.pattern = {112, 111, 110, 255}},               // UHR
    {.pattern = {54, 53, 52, 255}},                  // MIN
    {.pattern = {59, 60, 61, 62, 63, 64, 65, 255}},  // VIERTEL
    {.pattern = {55, 56, 57, 58, 59, 60, 61, 62, 63, 64, 65, 255}}, // DREIVIERTEL
    {.pattern = {76, 75, 74, 73, 255}},              // HALB
    {.pattern = {6, 15, 37, 38, 39, 40, 255}},       // NO WLAN
    {.pattern = {37, 38, 39, 40, 255}},              // WLAN
    {.pattern = {103, 255}},                         // D for DOT
    {.pattern = {96, 101, 119, 114, 255}},           // N-U-L-L
};

class LedCtrl {
 public:
  enum ColorType {
    minutesNumeral,
    minWord,
    preWord,
    quarterWord,
    hoursNumeral,
    clockWord
  };

  LedCtrl() {
    for (int i = 0; i < MAX_NUM_WORDS; i++) prevWordIndices[i] = WORDIDX_STOP;
  }

  ~LedCtrl() {}

  void setup(void) {
    FastLED.addLeds<NEOPIXEL, LED_DATA_PIN>(leds, NUM_LEDS);
  }

  void setColor(ColorType t, uint8_t hue, uint8_t sat, sint8_t lumaOffset, uint8_t _luma) {
    sint16_t luma = _luma + lumaOffset;
    if(luma < 0) luma = 0;
    if(luma > 255) luma = 255;
    CRGB c = CRGB(CHSV(hue, sat, (uint8_t)luma));
    Serial.print("LedCtrl::setColor: r,g,b=");
    Serial.print(c.r);
    Serial.print(",");
    Serial.print(c.g);
    Serial.print(",");
    Serial.println(c.b);
    switch (t) {
        case minutesNumeral:
          colorMinutesNumeral = c;
          break;
        case minWord:
          colorMinWord = c;
          break;
        case preWord:
          colorPreWord = c;
          break;
        case quarterWord:
          colorQuarterWord = c;
          break;
        case hoursNumeral:
          colorHoursNumeral = c;
          break;
        case clockWord:
          colorClockWord = c;
          break;
      }
  }

  void setLumaScale(uint8_t _lumaScale) {
    if(_lumaScale != lumaScale) {
      Serial.print("LedCtrl::setLumaScale: lumaScale=");
      Serial.println(_lumaScale);
      forceUpdate = true;
    }
    lumaScale = _lumaScale;
  }

  bool forceUpdate = false;

  void setClock(int hour, int minute) {
    if (hour != currentHour || minute != currentMinute || forceUpdate) {
      Serial.print("newClock: ");
      Serial.print(hour);
      Serial.print(":");
      Serial.println(minute);
      clearClockLeds();
      setClockLeds(hour, minute);
      FastLED.show();
      currentHour = hour;
      currentMinute = minute;
      forceUpdate = false;
    }
  }

  void clear(void) {
      clearClockLeds();
      FastLED.show();
  }

  void showNoWlan(void) {
      Serial.println("showNoWlan");
      CRGB col = CRGB::DarkRed;
      col.nscale8_video(lumaScale);
      clearClockLeds();
      const uint8_t *pattern = patterns[WORDIDX_NOWLAN].pattern;
      int letterCnt = 0;
      while (pattern[letterCnt] != 255) {
        leds[pattern[letterCnt]] = col;
        letterCnt++;
      }
      prevWordIndices[0] = WORDIDX_NOWLAN;
      prevWordIndices[1] = WORDIDX_STOP;
      FastLED.show();
  }

  void showWlan(CRGB col = CRGB::Green) {
      Serial.println("showWlan");
      col.nscale8_video(lumaScale);
      clearClockLeds();
      const uint8_t *pattern = patterns[WORDIDX_WLAN].pattern;
      int letterCnt = 0;
      while (pattern[letterCnt] != 255) {
        leds[pattern[letterCnt]] = col;
        letterCnt++;
      }
      prevWordIndices[0] = WORDIDX_WLAN;
      prevWordIndices[1] = WORDIDX_STOP;
      FastLED.show();
  }
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

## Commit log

2020-04-15 Intermediate development version
    - PCB done, awaiting delivery to test
    - FW:
    - WiFi AP to select home WiFi done
    - persistent storage working (WiFi, color, ...)
    - NTP (time retrieval) done
    - LED ctrl done, but not finally tested
    - Config web page done
    TODOs:
    - 3D printed matrix
    - Build real clock HW
    - Support dim by brightness measurement
    - Support off during night time
    - Show IP address after startup
    - Support button for factory reset
    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
    [wortuhr_pcb.kicad_pcb, wortuhr_pcb.sch]
2020-04-24 Added documentation
    Need to test now
    [Wortuhr_Rückteil.stl, Wortuhr_Vorderteil.stl]
2020-04-25 Added picture of initial PCB
2020-04-25 Added factory reset and disable softap after 15 mins
    [LedCtrl.h, main.cpp]
2020-04-26 Fixed pattern for VIER
    [LedCtrl.h]
2020-05-02 Online update of LED color while moving a slider
    Remove the test button since not needed any more
2020-05-21 Read current time on web i/f, update CRC lib
2020-05-31 New PCB V2
    [wortuhr_pcb.kicad_pcb, wortuhr_pcb.sch]
2020-05-31 Neuer Rahmen V2
    [Wortuhr_Rückteil.stl, Wortuhr_Vorderteil.stl]
2020-06-15 fix typo in comment
    [Persistent.h]
2020-06-15 lib ArduinoJson is missing from platoformio.ini
2020-06-28 Potential fix for issue #7
    There is a concurrent call of getTime in main.cpp. Once from the loop,
    once from the async web server. Solution:
    A) Move the time update out of the getTime function and call it only
    from the loop context (explicitly)
    B) Disable interrupts during reading the time, use old value in getTime
    in case an update is ongoing
    [Persistent.h, main.cpp]
2020-07-01 fix large webpage handling by using send_P() instead of send()
    [main.cpp]
2020-07-01 stop printing the WiFi passkey
2020-07-02 code cleanup & fix loading the colours into browser
    [LedCtrl.h, main.cpp]
2020-07-05 Fixed bug in getting and setting color
    [Persistent.h, main.cpp]
2020-07-05 Fixed missing break in LedCtrl.h
    [LedCtrl.h]
2020-07-21 auto detection of BH1750 and TSL2561 brightness sensors
2020-08-02 Switched to HSV for color selection
2021-08-13 stick to Arduino Core 2.x
    Arduino Core 3.x has breaking changes and FastLED does not behave well
    https://github.com/platformio/platform-espressif8266/releases/tag/v3.0.0
2022-07-24 added button 'LED-Test' to config page
2022-07-24 allow using the configuration button during connection attempt
2022-09-16 Minor improvement
    Replaced hard coded amount of patterns with compile time calc
    [LedCtrl.h]
